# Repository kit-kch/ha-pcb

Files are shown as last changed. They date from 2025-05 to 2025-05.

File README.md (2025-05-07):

# KCH Half Adder PCB

This repository contains schematic, layout and BOM for the KCH half adder PCB.
The PCB realizes a half adder using NAND gates, where some of the on-board components are left to be soldered by students as an exercise.

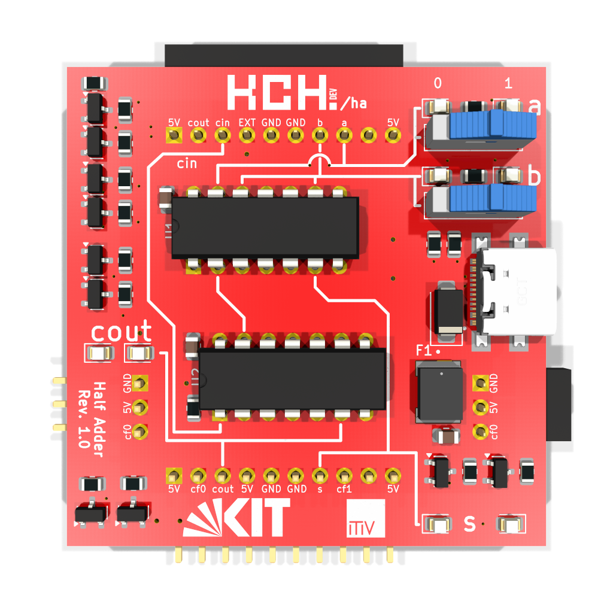
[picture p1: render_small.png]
PCB Render Image


Multiple PCBs can be connected to each other to form full adders or multi-bit carry ripple adders.
In addition to the PCB, we provide detailed documentation explaining the theory involved for both the PCB design and the digital circuit realization.

As the intended target audience is school students and their teachers, documentation is currently only available in German.

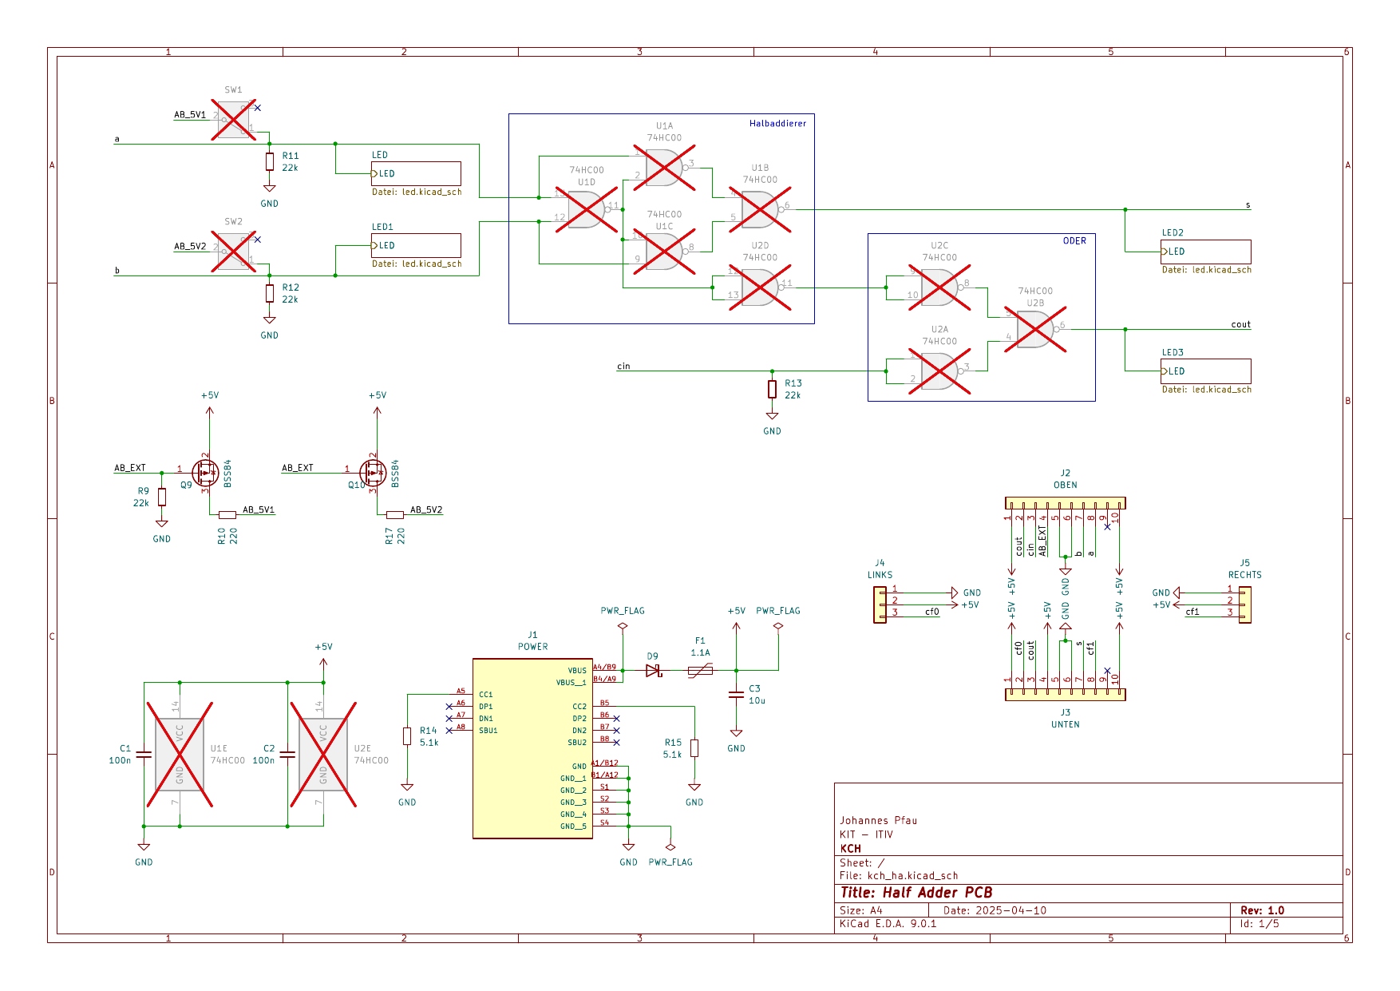
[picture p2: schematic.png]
PCB Schematic


## Ordering the PCBs

The initial batch of boards we have successfully used in a workshop has been ordered using JLCPCB's standard assembly service.
We had all the parts assembled, except for the switches and the 74HC00 ICs that are marked as do-not-place in the schematic.
Because of that, both-sided assembly and THT assembly is required.
The files we used to order from JLCPCB can be found in the production folder.

Please note: As the connectors are overlapping, the assembly service needs to add some spacers when paneling the design. Either panel yourself or let the factory know about this requirement.

Please also note that the boards should align when connected together.
PCB edges therefore need to be smooth so mouse bites should not be used.
Make sure to use v-score / v-cut panels instead.

## More Information and Documentation

* Project Website and Documentation: [kch.dev/ha](https://kch.dev/ha)
* Project Schematic: [kch_ha.pdf](kch_ha.pdf)

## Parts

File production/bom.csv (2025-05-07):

Designator | Footprint | Quantity | Value | LCSC Part #
C1, C2 | 0805 | 2 | 100n | C476766
C3 | 0805 | 1 | 10u | C5137471
D1, D3, D5, D7 | 0805 | 4 | BLAU | C98222
D2, D4, D6, D8 | 0805 | 4 | ROT | C94868
D9 | D_SMA | 1 | ~ | C2844169
F1 | FUSER_2016L050MR | 1 | 1.1A | C99564
J1 | GCT_USB4110-GF-A_REVB | 1 | POWER | C5143397
J2 | PinSocket_1x10_P2.54mm_Horizontal | 1 | OBEN | C22438151
J3 | PinHeader_1x10_P2.54mm_Horizontal | 1 | UNTEN | C492418
J4 | PinHeader_1x03_P2.54mm_Horizontal | 1 | LINKS | C492411
J5 | PinSocket_1x03_P2.54mm_Horizontal | 1 | RECHTS | C22438144
Q1, Q10, Q3, Q5, Q7, Q9 | SOT-23 | 6 | BSS84 | C112238
Q2, Q4, Q6, Q8 | SOT-23 | 4 | BSS138 | C78284
R1, R2, R3, R4, R5, R6, R7, R8 | 0805 | 8 | 680 | C17798
R10, R17 | 0805 | 2 | 220 | C2933537
R11, R12, R13, R9 | 0805 | 4 | 22k | C139902
R14, R15 | 0805 | 2 | 5.1k | C2930296

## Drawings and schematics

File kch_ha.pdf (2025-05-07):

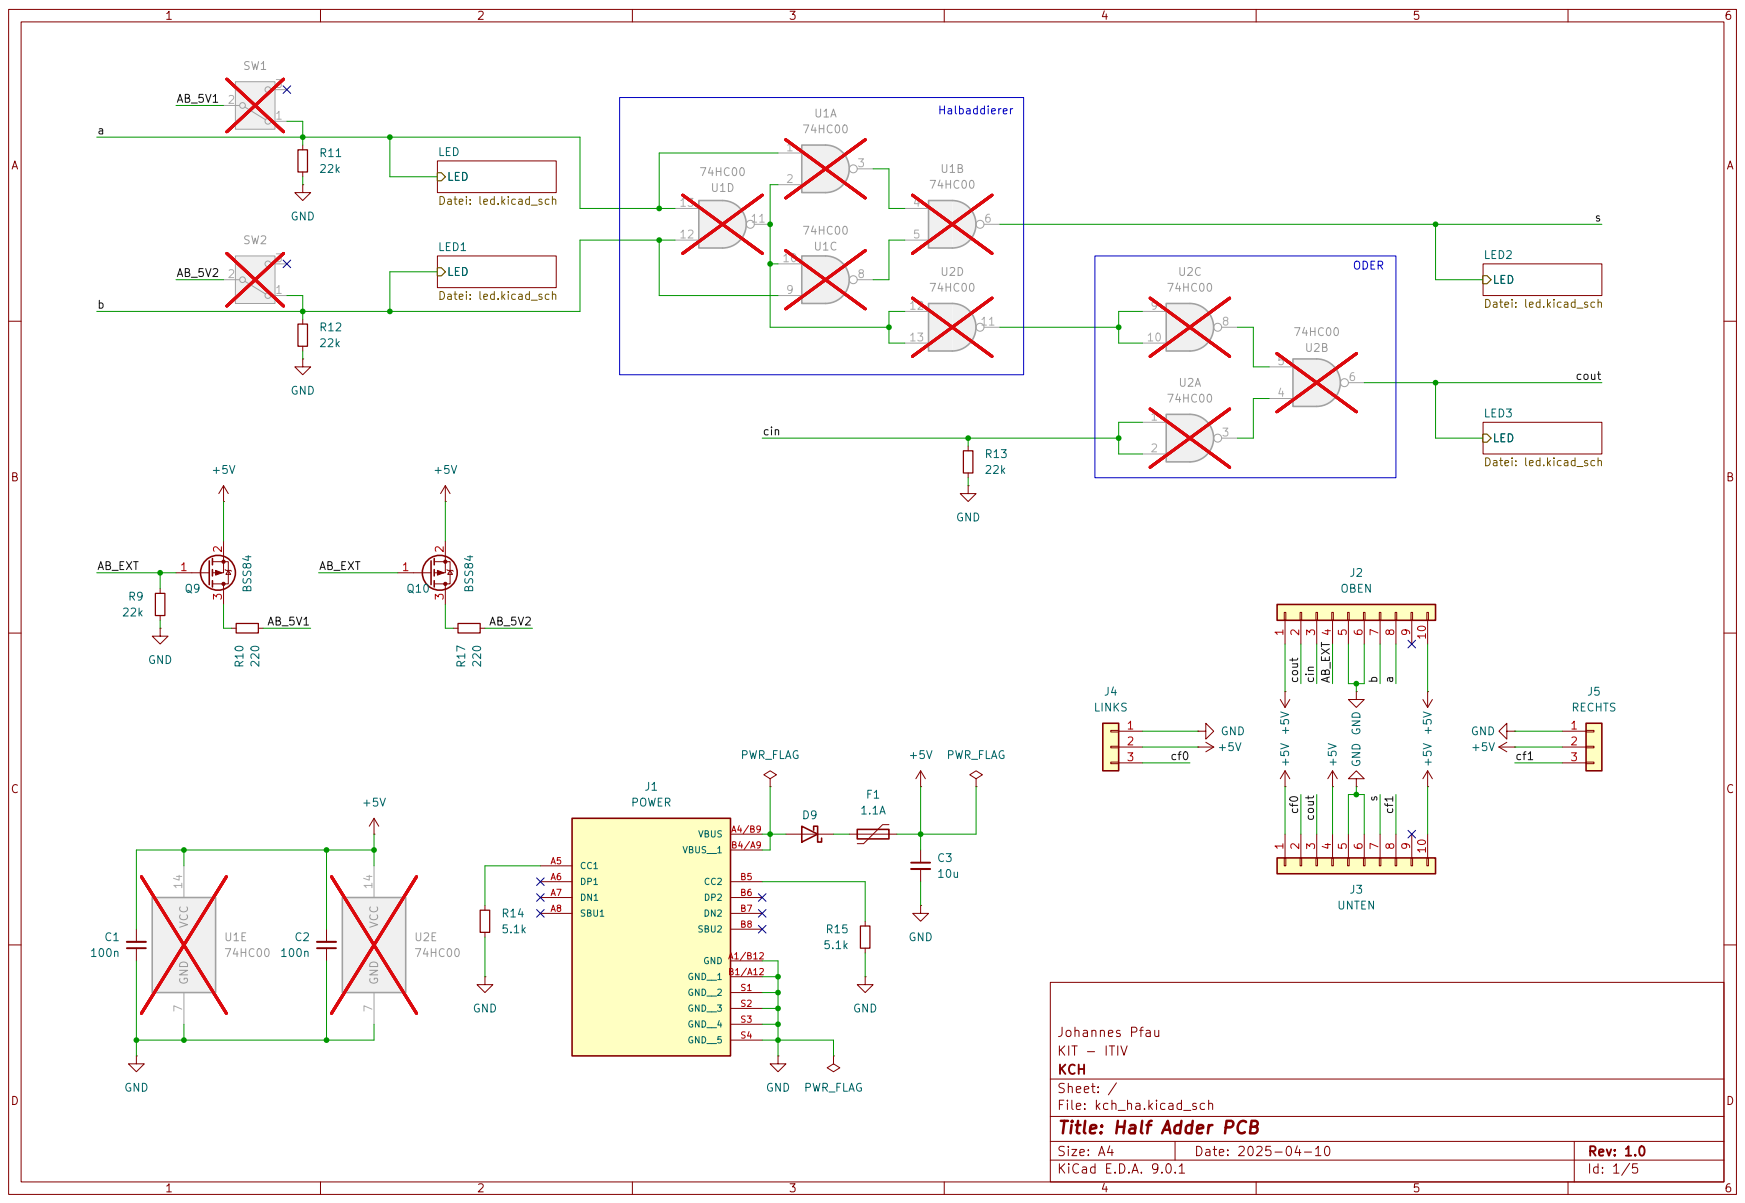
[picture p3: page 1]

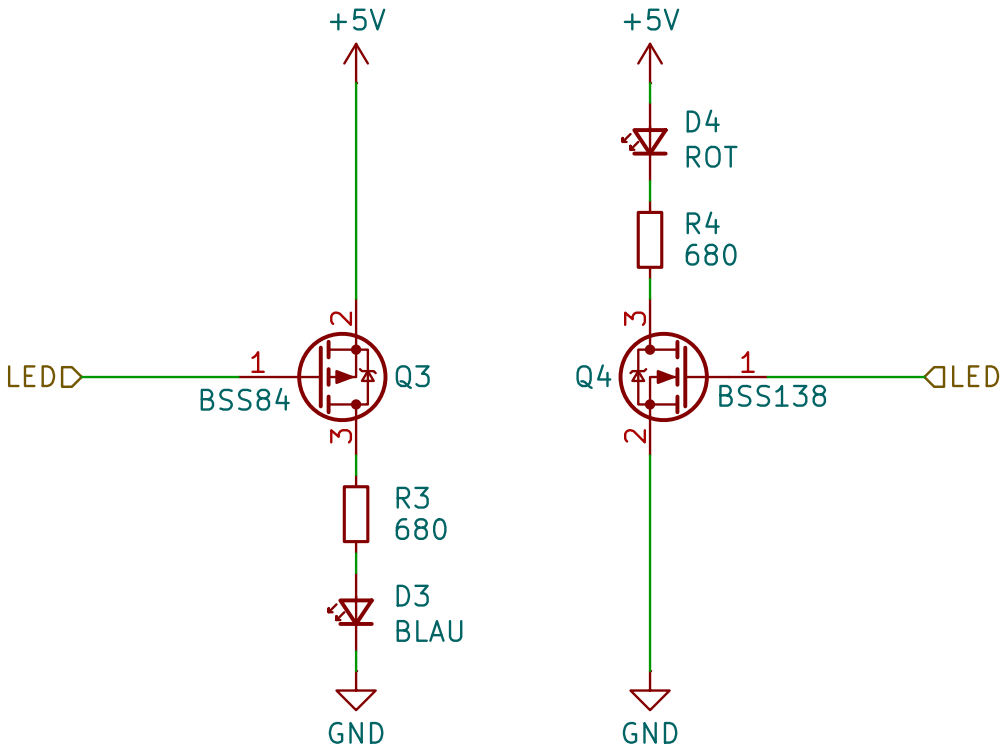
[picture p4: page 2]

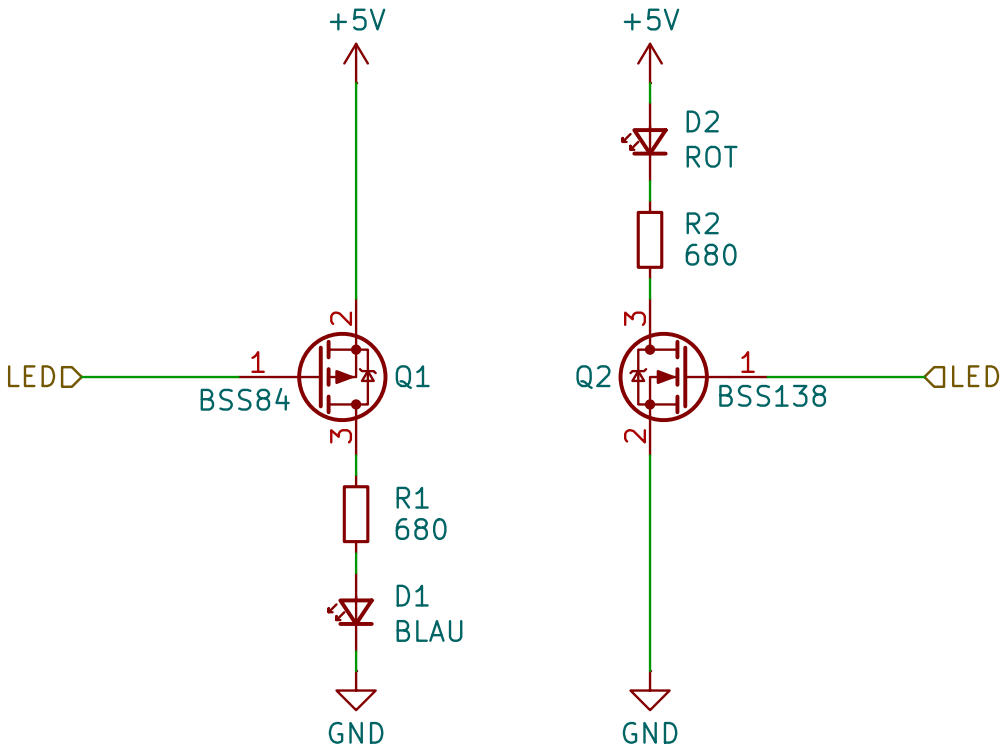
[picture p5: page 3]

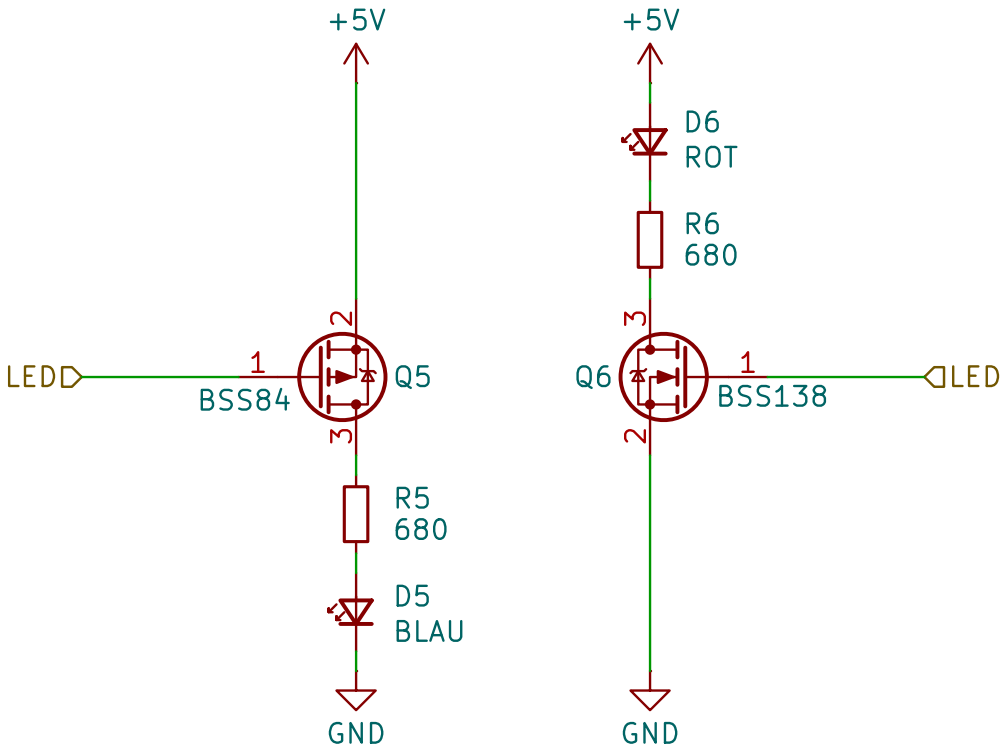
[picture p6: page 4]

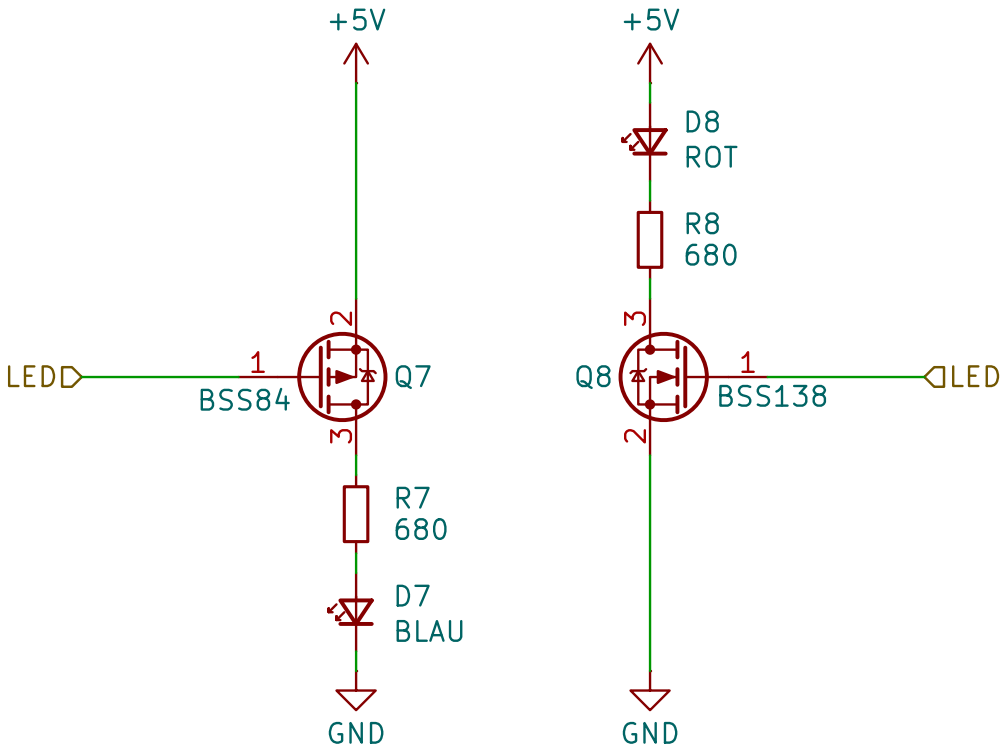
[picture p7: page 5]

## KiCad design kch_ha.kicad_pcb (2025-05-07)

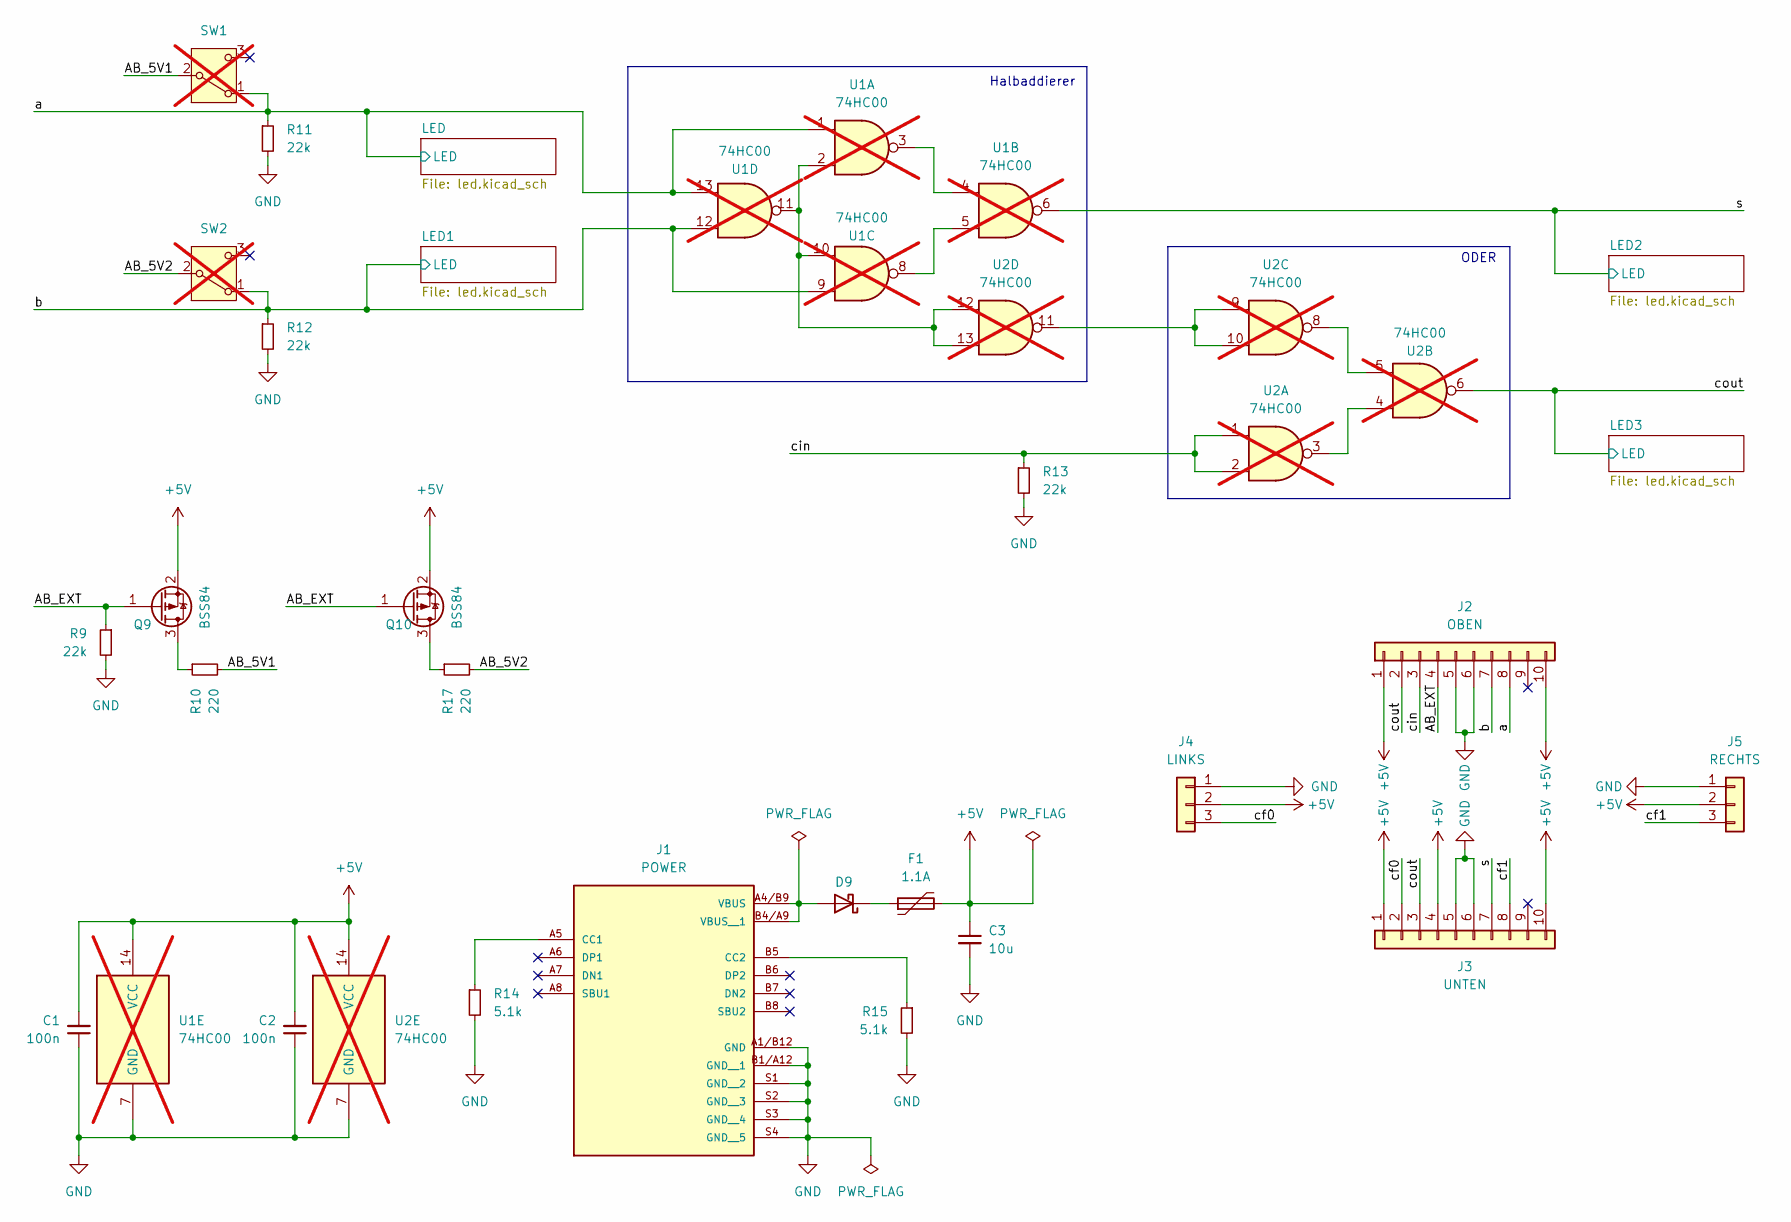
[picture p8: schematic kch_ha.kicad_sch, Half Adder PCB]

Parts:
C1, C2: 100n; C_0805_2012Metric; LCSC C476766
C3: 10u; C_0805_2012Metric; LCSC C5137471
D9: D_SMA; LCSC C2844169
F1: 1.1A; FUSER_2016L050MR; MPN 2016L050MR; LCSC C99564
J1: POWER; GCT_USB4110-GF-A_REVB; PARTREV B; LCSC C5143397
J2: OBEN; PinSocket_1x10_P2.54mm_Horizontal; MPN PPTC101LGBN-RC; LCSC C22438151
J3: UNTEN; PinHeader_1x10_P2.54mm_Horizontal; MPN PH1RB-10-UA; LCSC C492418
J4: LINKS; PinHeader_1x03_P2.54mm_Horizontal; MPN PH1RB-03-UA; LCSC C492411
J5: RECHTS; PinSocket_1x03_P2.54mm_Horizontal; MPN PPTC031LGBN-RC; LCSC C22438144
Q9, Q10: BSS84; SOT-23; MPN BSS84P; LCSC C112238
R9, R11, R12, R13: 22k; R_0805_2012Metric; LCSC C139902
R10, R17: 220; R_0805_2012Metric; LCSC C2933537
R14, R15: 5.1k; R_0805_2012Metric; LCSC C2930296
SW1: a; SW_Slide-03_Wuerth-WS-SLTV_10x2.5x6.4_P2.54mm; not fitted
SW2: b; SW_Slide-03_Wuerth-WS-SLTV_10x2.5x6.4_P2.54mm; not fitted
U1, U2: 74HC00; DIP-14_W7.62mm; MPN 74HC00; not fitted

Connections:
+5V: C1.2, C2.2, C3.1, F1.2, J2.1, J2.10, J3.1, J3.4, J3.10, J4.2, J5.2, Q9.2 (S), Q10.2 (S), U1.14 (VCC), U2.14 (VCC); also elsewhere on the board
/AB_5V1: R10.2, SW1.2 (B)
/AB_5V2: R17.2, SW2.2 (B)
/AB_EXT: J2.4, Q9.1 (G), Q10.1 (G), R9.1
/a: J2.8, R11.1, SW1.1 (A), U1.1, U1.13; also elsewhere on the board
/b: J2.7, R12.1, SW2.1 (A), U1.9, U1.12; also elsewhere on the board
/cf0: J3.2, J4.3
/cf1: J3.8, J5.3
/cin: J2.3, R13.1, U2.1, U2.2
/cout: J2.2, J3.3, U2.6; also elsewhere on the board
/s: J3.7, U1.6; also elsewhere on the board
GND: C1.1, C2.1, C3.2, J1.A1/B12 (GND), J1.B1/A12 (GND__1), J1.S1 (GND__2), J1.S2 (GND__3), J1.S3 (GND__4), J1.S4 (GND__5), J2.5, J2.6, J3.5, J3.6, J4.1, J5.1, R9.2, R11.2, R12.2, R13.2, R14.2, R15.2, U1.7 (GND), U2.7 (GND); also elsewhere on the board
unnamed: D9.2 (A), J1.A4/B9 (VBUS), J1.B4/A9 (VBUS__1)
unnamed: D9.1 (K), F1.1
unnamed: J1.A5 (CC1), R14.1
unnamed: J1.B5 (CC2), R15.1
unnamed: Q9.3 (D), R10.1
unnamed: Q10.3 (D), R17.1
unnamed: U1.3, U1.4
unnamed: U1.5, U1.8
unnamed: U1.2, U1.10, U1.11, U2.12, U2.13
unnamed: U2.3, U2.4
unnamed: U2.5, U2.8
unnamed: U2.9, U2.10, U2.11

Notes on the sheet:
Halbaddierer
ODER

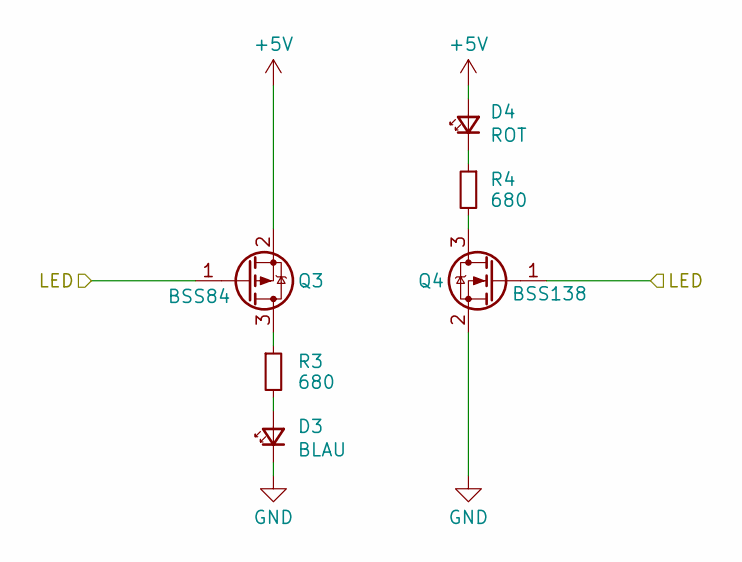
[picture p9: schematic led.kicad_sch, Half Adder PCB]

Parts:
D3: BLAU; LED_0805_2012Metric; MPN LTST-C170TBKT; LCSC C98222
D4: ROT; LED_0805_2012Metric; MPN LTST-C170KRKT; LCSC C94868
Q3: BSS84; SOT-23; MPN BSS84P; LCSC C112238
Q4: BSS138; SOT-23; MPN BSS138; LCSC C78284
R3, R4: 680; R_0805_2012Metric; LCSC C17798

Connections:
+5V: D4.2 (A), Q3.2 (S); also elsewhere on the board
/a: Q3.1 (G), Q4.1 (G); also elsewhere on the board
GND: D3.1 (K), Q4.2 (S); also elsewhere on the board
unnamed: D3.2 (A), R3.2
unnamed: D4.1 (K), R4.1
unnamed: Q3.3 (D), R3.1
unnamed: Q4.3 (D), R4.2

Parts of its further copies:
D1, D5, D7: BLAU; LED_0805_2012Metric; MPN LTST-C170TBKT; LCSC C98222
D2, D6, D8: ROT; LED_0805_2012Metric; MPN LTST-C170KRKT; LCSC C94868
Q1, Q5, Q7: BSS84; SOT-23; MPN BSS84P; LCSC C112238
Q2, Q6, Q8: BSS138; SOT-23; MPN BSS138; LCSC C78284
R1, R2, R5, R6, R7, R8: 680; R_0805_2012Metric; LCSC C17798

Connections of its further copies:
+5V: D2.2 (A), D6.2 (A), D8.2 (A), Q1.2 (S), Q5.2 (S), Q7.2 (S); also elsewhere on the board
/b: Q1.1 (G), Q2.1 (G); also elsewhere on the board
/cout: Q7.1 (G), Q8.1 (G); also elsewhere on the board
/s: Q5.1 (G), Q6.1 (G); also elsewhere on the board
GND: D1.1 (K), D5.1 (K), D7.1 (K), Q2.2 (S), Q6.2 (S), Q8.2 (S); also elsewhere on the board
unnamed: D1.2 (A), R1.2
unnamed: D2.1 (K), R2.1
unnamed: D5.2 (A), R5.2
unnamed: D6.1 (K), R6.1
unnamed: D7.2 (A), R7.2
unnamed: D8.1 (K), R8.1
unnamed: Q1.3 (D), R1.1
unnamed: Q2.3 (D), R2.2
unnamed: Q5.3 (D), R5.1
unnamed: Q6.3 (D), R6.2
unnamed: Q7.3 (D), R7.1
unnamed: Q8.3 (D), R8.2

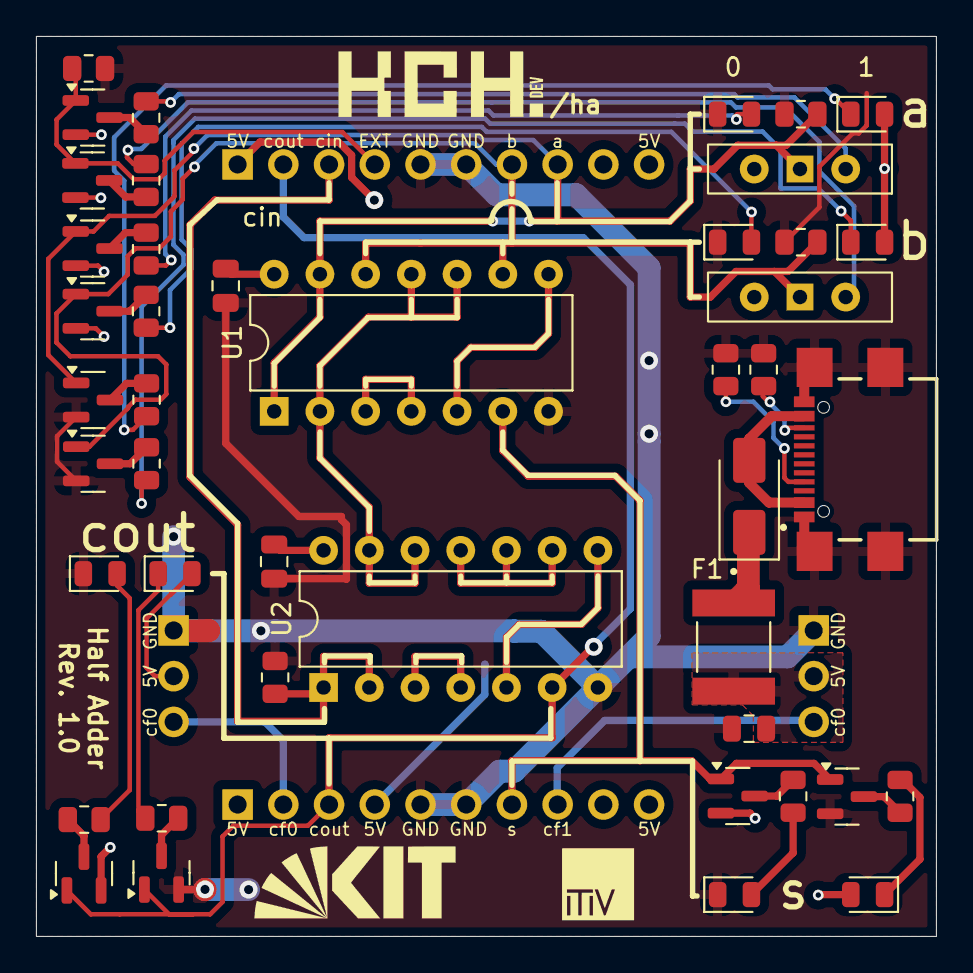
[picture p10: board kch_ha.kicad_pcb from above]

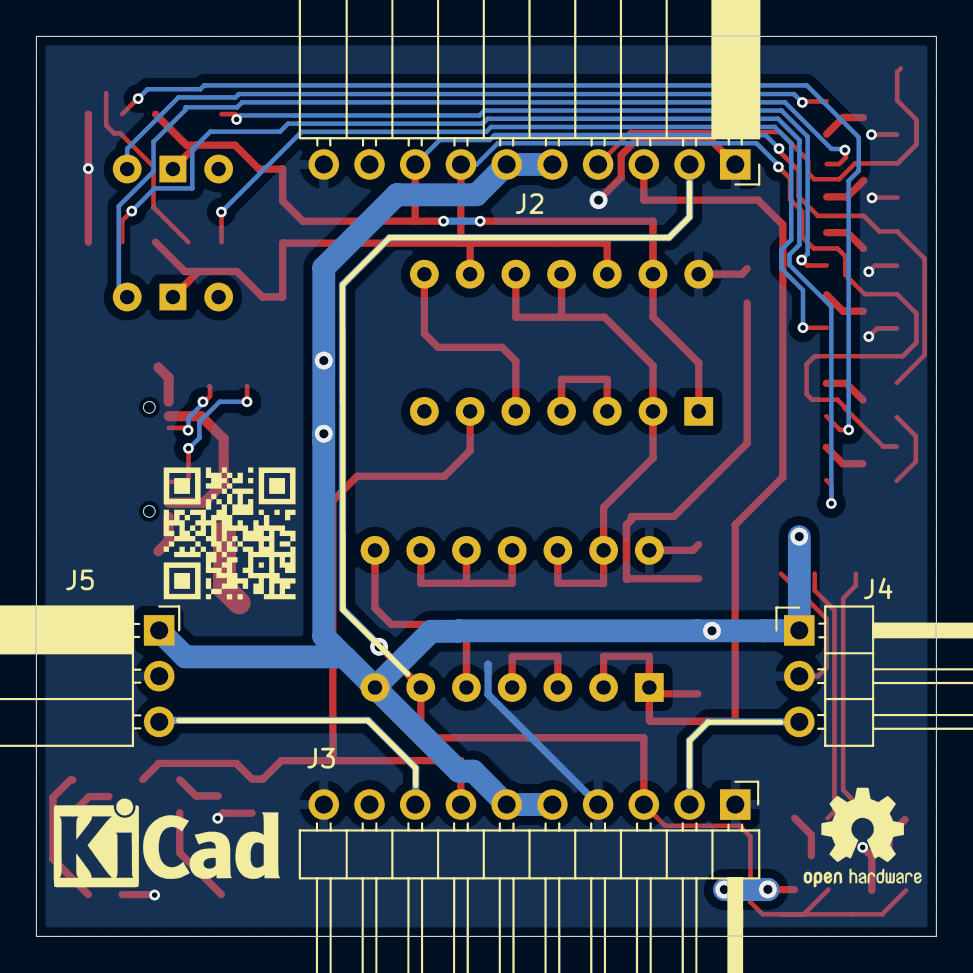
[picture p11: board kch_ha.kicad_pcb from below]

Board: 2 copper layers, 50.0 x 50.0 mm, 48 parts (4 on the bottom side), 40 nets.

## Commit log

2025-05-07 Initial public release
    [bom.csv, designators.csv, kch_ha.kicad_pcb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]
2025-05-08 Rerender schematic.png
